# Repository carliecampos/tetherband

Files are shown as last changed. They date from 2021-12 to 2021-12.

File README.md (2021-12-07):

# tetherband
Tetherband Board and Schematic Files 

All CAD files and libraries were created using EAGLE CAD. 

The Tetherband repository includes the board and schematic files for: 

A. PC-003 
   This is the prototyping board and has an arduino style pin header for analog control of each subsystem. There is no MCU included. 
B. PC-004
   This is the first completed board and includes the BM832 MCU and a JTAG connector for uploading firmware. The power button was not populated during testing. 
C. Tesseract Library
   This is the library used for all componenets added to PC-003 and PC-003 that were not included in the standard component libraries.

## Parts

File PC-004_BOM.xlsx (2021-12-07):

Obtained | Qty | Value | Device | Package | Parts | Description | Column1 | _1
Y | 1 |  | BM832 | BM832 | U2
Y | 1 | .01 | PCS1206DR0100ET | RESC3216X68N | R30 | Current Sense Resistors - SMD 1W 0.010 OHMS 0.5%
Y | 1 | .01 | R-US_R0603 | R0603 | R29 | RESISTOR, American symbol
Y | 2 | .1u | C-USC0603 | C0603 | C8, C11 | CAPACITOR, American symbol
Y | 1 | .47u | C-USC0603 | C0603 | C2 | CAPACITOR, American symbol
Y | 1 | 0.1u | C-USC0603 | C0603 | C12 | CAPACITOR, American symbol
Y | 1 | 100k | R-US_R0603 | R0603 | R6 | RESISTOR, American symbol
Y | 1 | 100Ω | SR0603FR-7T100RL | RESC1608X55N | R26 | Check prices
Y | 1 | 10118193-0001LF - micro USB | 10118193-0001LF | 101181930001LF | U1
Y | 3 | 10K | R-US_R0402 | R0402 | R3, R4, R33 | RESISTOR, American symbol
Y | 2 | 10k | R-US_R0402 | R0402 | R1, R10 | RESISTOR, American symbol
Y | 5 | 10u | CL21A106KOQNNNE | CAPC2012X140N | C1, C3, C5, C6, C9
Y | 1 | 150 | R-US_R0402 | R0402 | R2 | RESISTOR, American symbol
Y | 2 | 15ohm | SR0603JR-0715RL | RESC1608X55N | R13, R14 | Check prices
Y | 1 | 1N4148W-13-F | 1N4148W-13-F | SOD3715X135N | D1 | 1N4148W Series 2 A 100 V 400 mW Surface Mount Fast Switching Diode - SOD-123 Check prices
Y | 9 | 1k | CRCW06031K00FKEAC | RESC1608X55N | R7, R8, R9, R12, R15, R17, R18, R19, R24
Y | 1 | 2.2u | C-USC0603 | C0603 | C7 | CAPACITOR, American symbol
Y | 3 | 25ohm | RQ73C2A25R5BTD | RESC2012X65N | R20, R21, R23 | Check prices
Y | 1 | 300Ω | CRCW1206300RFKEAC | RESC3015X65N | R27 | Check prices
Y | 3 | 35ohm | RT0603BRD0735R2L | RESC1608X55N | R16, R22, R25
Y | 1 | 3kΩ | CR1206-FX-3001ELF | RESC3216X75N | R28
Y | 1 | 453k | R-US_R0402 | R0402 | R5 | RESISTOR, American symbol
Y | 2 | 5.23k | R-US_R0603 | R0603 | R31, R32 | RESISTOR, American symbol
Y | 1 | 50ohm | RT0402BRE0750RL | RESC1005X35N | R11
 | 1 | 61201021621 | 61201021621 | SHDR10W64P254_2X5_2036X885X925 | J1 | 10 way 2.54mm male box Header Wurth Elektronik 612 Series, 2.54mm Pitch 10 Way 2 Row Straight PCB Header, Solder Termination, 3A
Y | 1 | 8.2p | C-USC0402K | C0402K | C4 | CAPACITOR, American symbol
N - only 1 | 1 | BQ27421YZFR-G1A | BQ27421YZFR-G1A | BGA9C50P3X3_158X162X62 | IC3
N/A | 1 | Batt Connect | L02P | L02P | SV1 | AMP MT CONNECTOR
Y | 1 | DMP2008UFG7 | DMP2008UFG | DMP2008UFG7 | Q1
Y | 2 | GSOT04-G3-18 | GSOT04-G3-18 | SOT23 | D2, D3
 | 1 | LL3303F065QG | LL3303F065QG | LL3303F065QG | G1
Y | 1 | LRTBGVSR-U4V2-JW+A6BB-D8+S2U2- | LRTBGVSR-U4V2-JW+A6BB-D8+S2U2- | LRTBGVSRU4V2JWA6BBD8S2U27Z20S | LED2 | Standard LEDs - SMD RGB LED OSIRE E3635
N/A | 6 | LSP10 | LSP10 | LSP10 | GND, LED, NEG(-), OUT, POS(+), VDD | SOLDER PAD drill 1.0 mm, distributor Buerklin, 12H555
N - only 3 | 1 | MCP73831/OT | MCP73831/OT | SOT23-5L | IC2 | MCP73831/2
Y | 8 | MMBT3904 | MMBT3904-7-FNSMD | SOT23 | Q2, Q3, Q4, Q5, Q6, Q7, Q8, Q9
Y | 1 | ORANGE | SML-D15YWT86CORANGE | SML0603 | LED5
 | 1 | PRT-16279 | PRT-16279 | PRT16279 | J2 | ARDUINO NANO STACKABLE HEADERS
Y | 1 | PS1240P02BT Speaker | PS1240P02BT | PS1240P02BT | LS1 | Audio Indicators & Alerts Round 12.2mmx6.5mm 4kHz Vin=3V
Y | 1 | PURPLE | APTR3216-VFX | LEDC3216X125N | LED3
Y | 1 | RED | 150060RS75000 | LEDC1608X80N | LED1
 | 1 | SDR0403-2R2ML | SDR0403-2R2ML | SDR04032R2ML | L1 | Bourns SDR0403 Series Type SMD Wire-wound SMD Inductor with a Ferrite DR Core, 2.2 uH +/-20% 2.6A Idc Q:28
N/A | 19 | TESTPOINT | TESTPOINT | TESTPOINT_PAD-036 | TP1, TP2, TP3, TP4, TP5, TP6, TP8, TP11, TP12, TP13, TP14, TP15, TP16, TP17, TP18, TP19, TP20, TP21, TP22
Y | 1 | TLV62568DRLRSOT-5X3 | TLV62568DRLRSOT-5X3 | SOT50P160X60-6N | U$1
Y | 1 | W3102 | W3102 | W3102 | ANT1 | Antennas Ant Embedded NFC 13.56MHz
Y | 1 | YELLOW | SML-D15YWT86CYELLOW | SML0603 | LED4
Y | 1 | MMBT222A BJT Transistor | MMBT2222A-AU_R1_000A1 |  | ?

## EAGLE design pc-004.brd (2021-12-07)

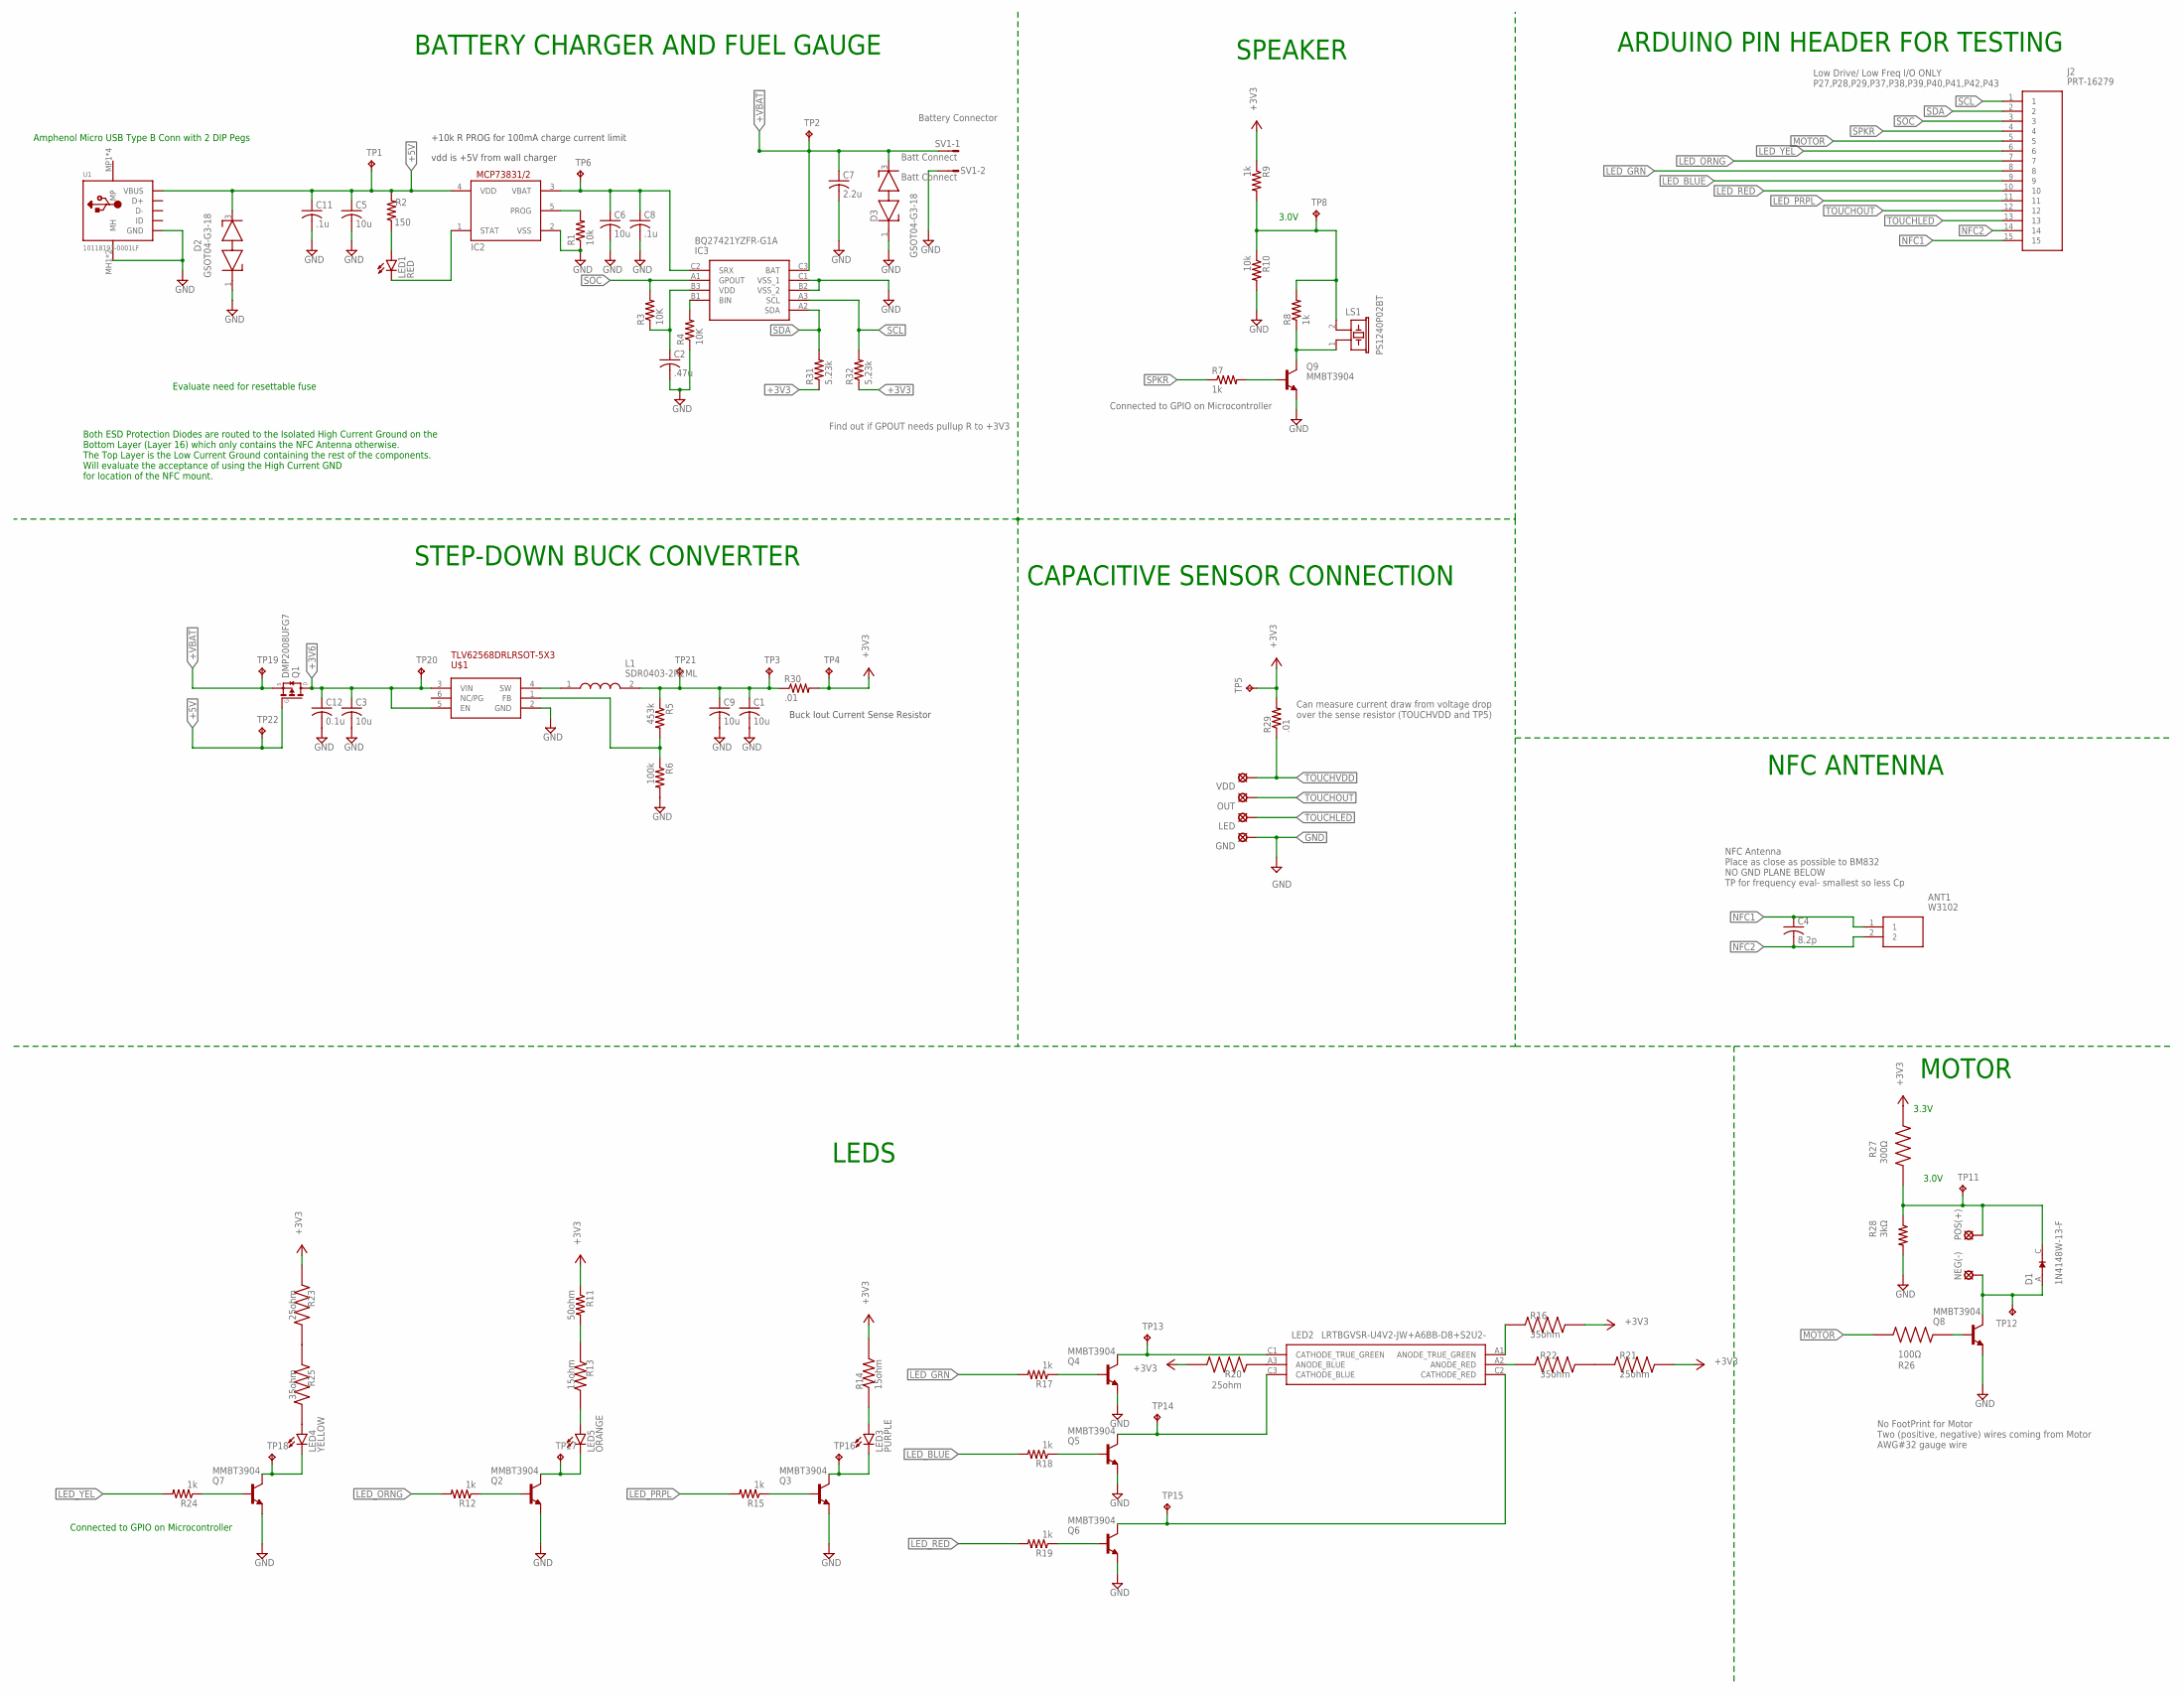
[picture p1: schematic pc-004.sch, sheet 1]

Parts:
ANT1: W3102
C1, C3, C5, C6, C9: 10u; CAPC2012X140N
C2: .47u; C0603
C4: 8.2p; C0402K
C7: 2.2u; C0603
C8, C11: .1u; C0603
C12: 0.1u; C0603
D1: 1N4148W-13-F; SOD3715X135N
D2, D3: GSOT04-G3-18; SOT23
GND: LSP10
IC2: MCP73831/OT; SOT23-5L
IC3: BQ27421YZFR-G1A; BGA9C50P3X3_158X162X62
J2: PRT-16279; PRT16279
L1: SDR0403-2R2ML; SDR04032R2ML
LED: LSP10
LED1: RED; LEDC1608X80N
LED2: LRTBGVSR-U4V2-JW+A6BB-D8+S2U2-; LRTBGVSRU4V2JWA6BBD8S2U27Z20S
LED3: PURPLE; LEDC3216X125N
LED4: YELLOW; SML0603
LED5: ORANGE; SML0603
LS1: PS1240P02BT
NEG(-): LSP10
OUT: LSP10
POS(+): LSP10
Q1: DMP2008UFG7
Q2, Q3, Q4, Q5, Q6, Q7, Q8, Q9: MMBT3904; SOT23
R1, R10: 10k; R0402
R2: 150; R0402
R3, R4: 10K; R0402
R5: 453k; R0402
R6: 100k; R0603
R7, R8, R9, R12, R15, R17, R18, R19, R24: 1k; RESC1608X55N
R11: 50ohm; RESC1005X35N
R13, R14: 15ohm; RESC1608X55N
R16, R22, R25: 35ohm; RESC1608X55N
R20, R21, R23: 25ohm; RESC2012X65N
R26: 100Ω; RESC1608X55N
R27: 300Ω; RESC3015X65N
R28: 3kΩ; RESC3216X75N
R29: .01; R0603
R30: .01; RESC3216X68N
R31, R32: 5.23k; R0603
SV1: Batt Connect; L02P
TP1, TP2, TP3, TP4, TP5, TP6, TP8, TP11, TP12, TP13, TP14, TP15, TP16, TP17, TP18, TP19, TP20, TP21, TP22: TESTPOINT; TESTPOINT_PAD-036
U1: 10118193-0001LF; 101181930001LF
U$1: TLV62568DRLRSOT-5X3; SOT50P160X60-6N
VDD: LSP10

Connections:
+3V3: R9.1, R11.1, R14.2, R16.2, R20.2, R21.2, R23.1, R27.1, R29.2, R30.2, R31.1, R32.1, TP4.1, TP5.1; also elsewhere on the board
+3V6: C3.1, C12.1, Q1.5 (D), Q1.6 (D), Q1.7 (D), Q1.8 (D), Q1.9 (D), TP20.1, U$1.3 (VIN), U$1.5 (EN)
+5V: C5.1, C11.1, D2.3 (K2), IC2.4 (VDD), Q1.4 (G), R2.2, TP1.1, TP22.1, U1.1 (VBUS)
+VBAT: C7.1, D3.3 (K2), IC3.C3 (BAT), Q1.1 (S), Q1.2 (S), Q1.3 (S), SV1.1, TP2.1, TP19.1
GND: C1.2, C2.2, C3.2, C5.2, C6.2, C7.2, C8.2, C9.2, C11.2, C12.2, D2.1 (K1), D3.1 (K1), GND.MP, IC2.2 (VSS), IC3.B2 (VSS_2), IC3.C1 (VSS_1), Q2.2 (E), Q3.2 (E), Q4.2 (E), Q5.2 (E), Q6.2 (E), Q7.2 (E), Q8.2 (E), Q9.2 (E), R1.1, R4.1, R6.2, R10.2, R28.2, SV1.2, U1.5 (GND), U1.MH1 (MH), U1.MH2 (MH), U$1.2 (GND); also elsewhere on the board
LED_BLUE: J2.9, R18.2; also elsewhere on the board
LED_GRN: J2.8, R17.2; also elsewhere on the board
LED_ORNG: J2.7, R12.2; also elsewhere on the board
LED_PRPL: J2.11, R15.2; also elsewhere on the board
LED_RED: J2.10, R19.2; also elsewhere on the board
LED_YEL: J2.6, R24.2; also elsewhere on the board
MOTOR: J2.5, R26.1; also elsewhere on the board
unnamed: Q9.1 (B), R7.2
unnamed: LS1.1, Q9.3 (C), R8.1
unnamed: IC2.5 (PROG), R1.2
unnamed: L1.1, U$1.4 (SW)
unnamed: R5.2, R6.1, U$1.1 (FB)
unnamed: IC2.1 (STAT), LED1.1 (C)
unnamed: LED1.2 (A), R2.1
unnamed: Q8.1 (B), R26.2
unnamed: IC3.B1 (BIN), R4.2
unnamed: LS1.2, R8.2, R9.2, R10.1, TP8.1
unnamed: D1.C (K), POS(+).MP, R27.2, R28.1, TP11.1
unnamed: Q2.1 (B), R12.1
unnamed: LED5.C, Q2.3 (C), TP17.1
unnamed: R11.2, R13.1
unnamed: LED5.A, R13.2
unnamed: C1.1, C9.1, L1.2, R5.1, R30.1, TP3.1, TP21.1
unnamed: Q3.1 (B), R15.1
unnamed: LED3.1 (C), Q3.3 (C), TP16.1
unnamed: LED3.2 (A), R14.1
unnamed: R21.1, R22.2
unnamed: Q4.1 (B), R17.1
unnamed: LED2.C1 (CATHODE_TRUE_GREEN), Q4.3 (C), TP13.1
unnamed: D1.A, NEG(-).MP, Q8.3 (C), TP12.1
unnamed: Q5.1 (B), R18.1
unnamed: C6.1, C8.1, IC2.3 (VBAT), IC3.C2 (SRX), TP6.1
unnamed: Q6.1 (B), R19.1
unnamed: LED2.C3 (CATHODE_BLUE), Q5.3 (C), TP14.1
unnamed: LED2.A3 (ANODE_BLUE), R20.1
unnamed: LED2.A1 (ANODE_TRUE_GREEN), R16.1
unnamed: LED2.C2 (CATHODE_RED), Q6.3 (C), TP15.1
unnamed: LED2.A2 (ANODE_RED), R22.1
unnamed: Q7.1 (B), R24.1
unnamed: LED4.C, Q7.3 (C), TP18.1
unnamed: LED4.A, R25.2
unnamed: R23.2, R25.1
unnamed: C2.1, IC3.B3 (VDD), R3.1
NFC1: ANT1.1, C4.1, J2.15; also elsewhere on the board
NFC2: ANT1.2, C4.2, J2.14; also elsewhere on the board
SCL: IC3.A3 (SCL), J2.1, R32.2; also elsewhere on the board
SDA: IC3.A2 (SDA), J2.2, R31.2; also elsewhere on the board
SOC: IC3.A1 (GPOUT), J2.3, R3.2; also elsewhere on the board
SPKR: J2.4, R7.1; also elsewhere on the board
TOUCHLED: J2.13, LED.MP
TOUCHOUT: J2.12, OUT.MP; also elsewhere on the board
TOUCHVDD: R29.1, VDD.MP

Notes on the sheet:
NFC Antenna Place as close as possible to BM832 NO GND PLANE BELOW TP for frequency eval- smallest so less Cp
vdd is +5V from wall charger
+10k R PROG for 100mA charge current limit
Battery Connector
Low Drive/ Low Freq I/O ONLY P27,P28,P29,P37,P38,P39,P40,P41,P42,P43
Connected to GPIO on Microcontroller
3.0V
3.3V
No FootPrint for Motor Two (positive, negative) wires coming from Motor AWG#32 gauge wire
Evaluate need for resettable fuse
Buck Iout Current Sense Resistor
NFC ANTENNA
CAPACITIVE SENSOR CONNECTION
SPEAKER
BATTERY CHARGER AND FUEL GAUGE
STEP-DOWN BUCK CONVERTER
LEDS
MOTOR
ARDUINO PIN HEADER FOR TESTING
Find out if GPOUT needs pullup R to +3V3
Can measure current draw from voltage drop over the sense resistor (TOUCHVDD and TP5)
Amphenol Micro USB Type B Conn with 2 DIP Pegs
Both ESD Protection Diodes are routed to the Isolated High Current Ground on the Bottom Layer (Layer 16) which only contains the NFC Antenna otherwise. The Top Layer is the Low Current Ground containing the rest of the components. Will evaluate the acceptance of using the High Current GND for locat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

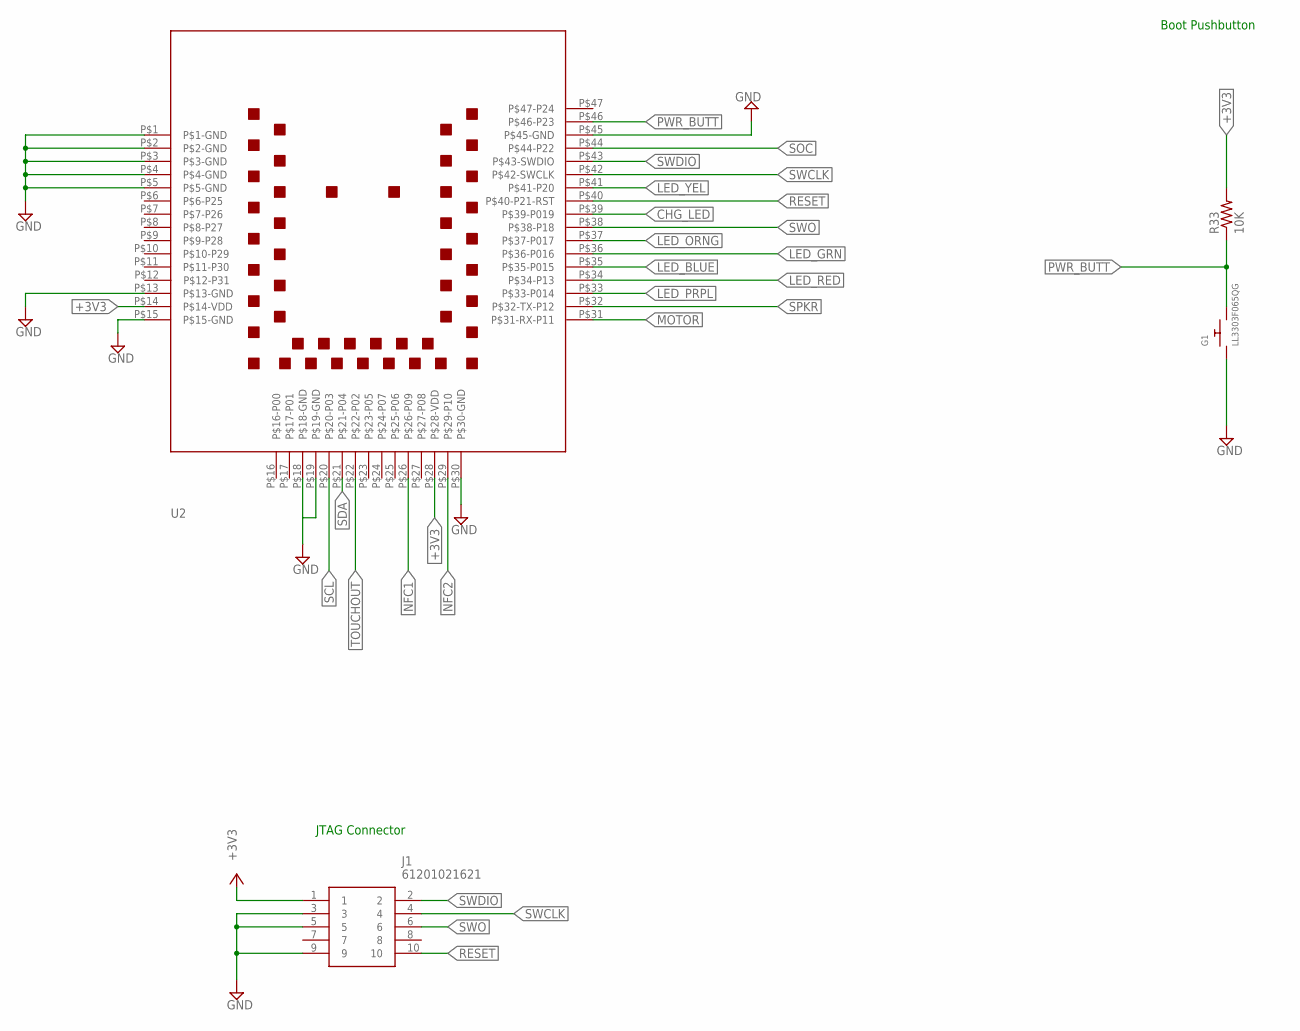
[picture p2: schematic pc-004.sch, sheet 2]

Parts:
G1: LL3303F065QG
J1: 61201021621; SHDR10W64P254_2X5_2036X885X925
R33: 10K; R0402
U2: BM832

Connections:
+3V3: J1.1, R33.2, U2.P$14 (P$14-VDD), U2.P$28 (P$28-VDD); also elsewhere on the board
CHG_LED: U2.P$39 (P$39-P019)
GND: G1.P$1, G1.P$2, J1.3, J1.5, J1.9, U2.P$1 (P$1-GND), U2.P$2 (P$2-GND), U2.P$3 (P$3-GND), U2.P$4 (P$4-GND), U2.P$5 (P$5-GND), U2.P$13 (P$13-GND), U2.P$15 (P$15-GND), U2.P$18 (P$18-GND), U2.P$19 (P$19-GND), U2.P$30 (P$30-GND), U2.P$45 (P$45-GND); also elsewhere on the board
LED_BLUE: U2.P$35 (P$35-P015); also elsewhere on the board
LED_GRN: U2.P$36 (P$36-P016); also elsewhere on the board
LED_ORNG: U2.P$37 (P$37-P017); also elsewhere on the board
LED_PRPL: U2.P$33 (P$33-P014); also elsewhere on the board
LED_RED: U2.P$34 (P$34-P13); also elsewhere on the board
LED_YEL: U2.P$41 (P$41-P20); also elsewhere on the board
MOTOR: U2.P$31 (P$31-RX-P11); also elsewhere on the board
NFC1: U2.P$26 (P$26-P09); also elsewhere on the board
NFC2: U2.P$29 (P$29-P10); also elsewhere on the board
PWR_BUTT: G1.P$3, G1.P$4, R33.1, U2.P$46 (P$46-P23)
RESET: J1.10, U2.P$40 (P$40-P21-RST)
SCL: U2.P$20 (P$20-P03); also elsewhere on the board
SDA: U2.P$21 (P$21-P04); also elsewhere on the board
SOC: U2.P$44 (P$44-P22); also elsewhere on the board
SPKR: U2.P$32 (P$32-TX-P12); also elsewhere on the board
SWCLK: J1.4, U2.P$42 (P$42-SWCLK)
SWDIO: J1.2, U2.P$43 (P$43-SWDIO)
SWO: J1.6, U2.P$38 (P$38-P18)
TOUCHOUT: U2.P$22 (P$22-P02); also elsewhere on the board

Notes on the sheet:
Boot Pushbutton
JTAG Connector

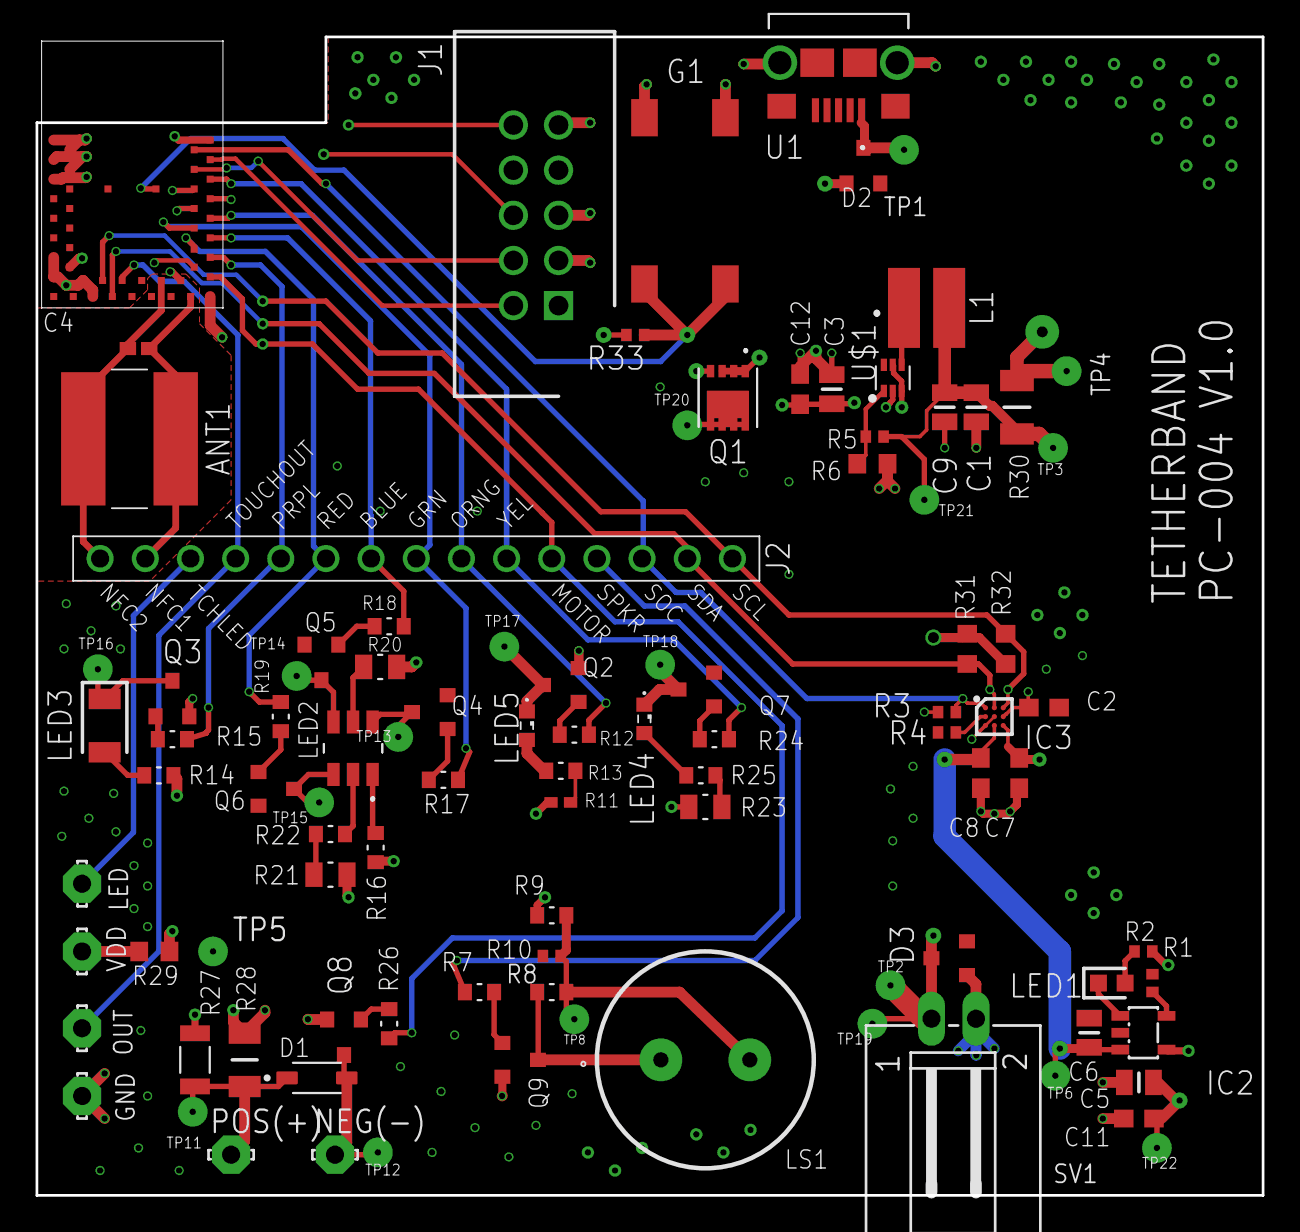
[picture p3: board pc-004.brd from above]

Board: 4 copper layers, 69.0 x 65.2 mm, 98 parts (0 on the bottom side), 62 nets.
